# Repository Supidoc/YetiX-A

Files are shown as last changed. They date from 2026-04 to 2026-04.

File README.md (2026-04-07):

# YetiX-A

Small development board for the NXP MCX-A series MCUs.

YetiX-A is designed to be compact while still exposing most peripherals needed for firmware development, board bring-up, and protocol testing.

## Features

- SPI EEPROM
- SPI micro SD card slot
- CAN transceiver with optional bus termination
- USB-C connector with ISP button support
- 42 board pins exposing almost all MCU peripherals
- 10-pin ARM Cortex debug connector

## Pin Out

Most MCU pins are routed directly to board pins.

Some signals (for example SPI1 MISO, MOSI, and SCK) are internally connected to onboard peripherals and are still exposed as board pins. Other signals (for example debug pins and chip select lines) are only internally connected and not exposed.

For the exact mapping of MCU pins to board pins, see:

- [assets/PIN_Functions.csv](assets/PIN_Functions.csv)

## Quick Start

1. Power the board via the USB-C receptecal or the 5V Pin
2. Connect a debugger to the 10-pin Cortex debug header, or use ISP mode over USB.
3. Flash a minimal firmware project (for example, a GPIO blink) to verify toolchain and board bring-up.

## Programming And Debug

### SWD/JTAG Debug Header

YetiX-A includes a 10-pin ARM Cortex debug connector for standard MCU debugging workflows.

Recommended usage:

1. Power the board from USB-C or the intended external source.
2. Connect your debug probe to the Cortex header.
3. Use your preferred IDE/debug server to connect and flash.

### USB ISP Mode

The board supports ISP using the USB-C interface.

Typical flow:

1. Hold the ISP button.
2. Connect USB or reset the target if already connected.
3. Release the button.
4. Drag and drop the .uf2 file to the mass storage device.

## Onboard Peripherals

### SPI EEPROM (ST M95256-DF)

- Intended for non-volatile parameter/configuration storage.
- Shares SPI1 bus with SD-card and other externally connected devices.

### SPI micro SD Slot

- Intended for logging, file storage, or data exchange.
- Shares SPI1 bus with EEPROM and other externally connected devices.
- Switch to detect card insertion.

### CAN Transceiver (NXP TJA1042BT)

- 5V CAN Transceiver
- Optional footprints for termination.

## Documentation And Design Files

### KiCad Source

- Schematic: [YetiX-A_DevBoard.kicad_sch](YetiX-A_DevBoard.kicad_sch)
- PCB: [YetiX-A_DevBoard.kicad_pcb](YetiX-A_DevBoard.kicad_pcb)
- Project: [YetiX-A_DevBoard.kicad_pro](YetiX-A_DevBoard.kicad_pro)

### Exported Documentation

- Schematic PDF: [FabData/YetiX-A_Schematic.pdf](FabData/YetiX-A_Schematic.pdf)
- PCB layout PDF: [FabData/YetiX-A_PCB_Layout.pdf](FabData/YetiX-A_PCB_Layout.pdf)

### Manufacturing Outputs

All Documents for fabrication can be found in [FabData](FabData)

## Hardware Revisions

| Revision | Date | Notes |
| --- | --- | --- |
| 0.0.1 | - | Initial production package |
| 0.0.2 | - | Added optional CAN Termination |

## License

See [LICENSE](LICENSE).

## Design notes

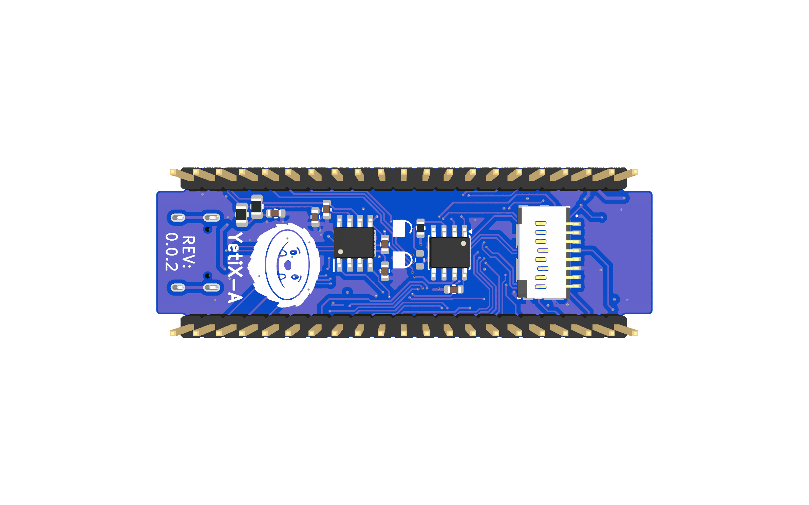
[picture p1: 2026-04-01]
FabData/dok/YetiX-A_bottom_view.png

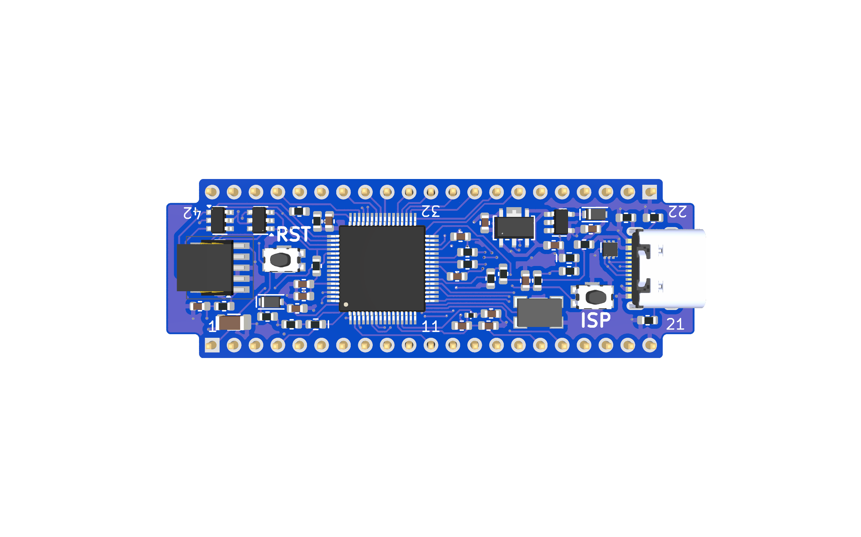
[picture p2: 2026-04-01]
FabData/dok/YetiX-A_top_view.png

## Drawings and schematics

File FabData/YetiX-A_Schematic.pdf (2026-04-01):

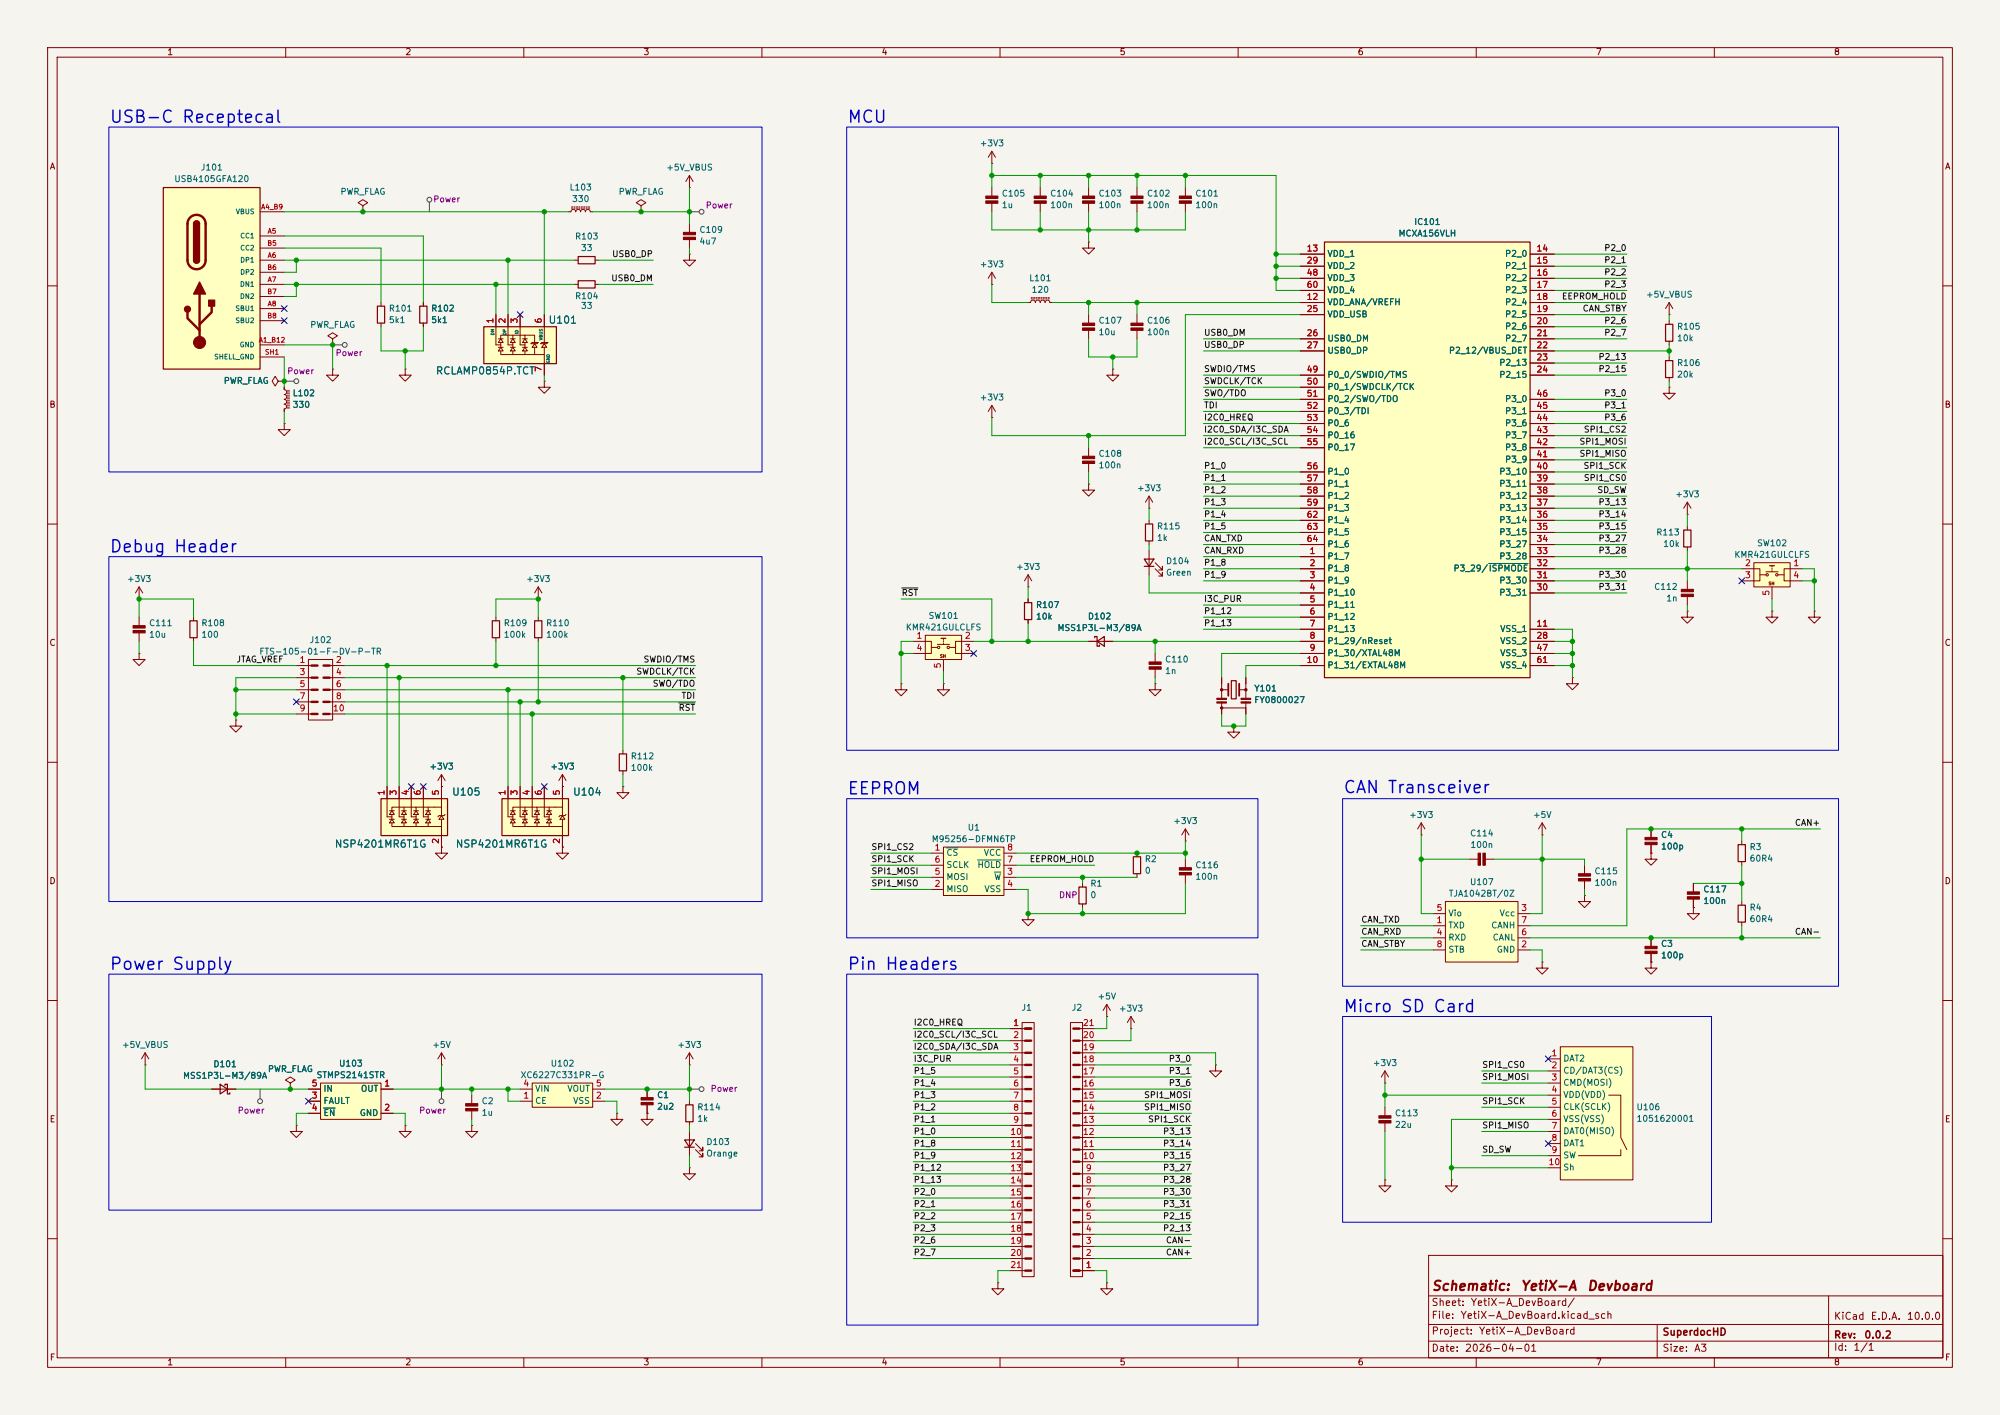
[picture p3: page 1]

5 | 6 | SWO/TDO

Sheet: YetiX-A_DevBoard/ File: YetiX-A_DevBoard.kicad_sch
Project: YetiX-A_DevBoard | SuperdocHD | KiCad E.D.A. 10.0.0 Rev: 0.0.2 | F Date: 2026-04-01

Size: A3 | Id: 1/1

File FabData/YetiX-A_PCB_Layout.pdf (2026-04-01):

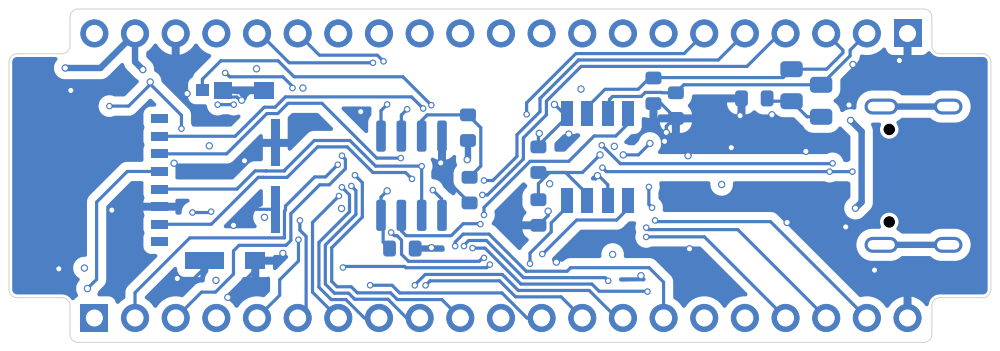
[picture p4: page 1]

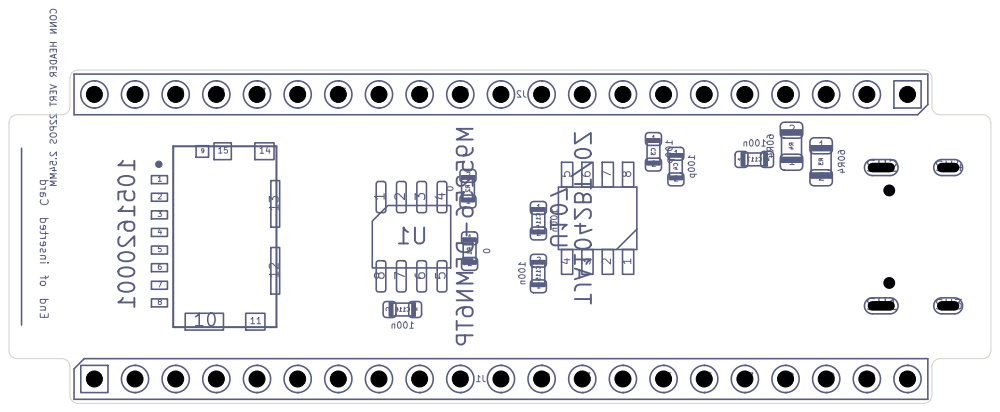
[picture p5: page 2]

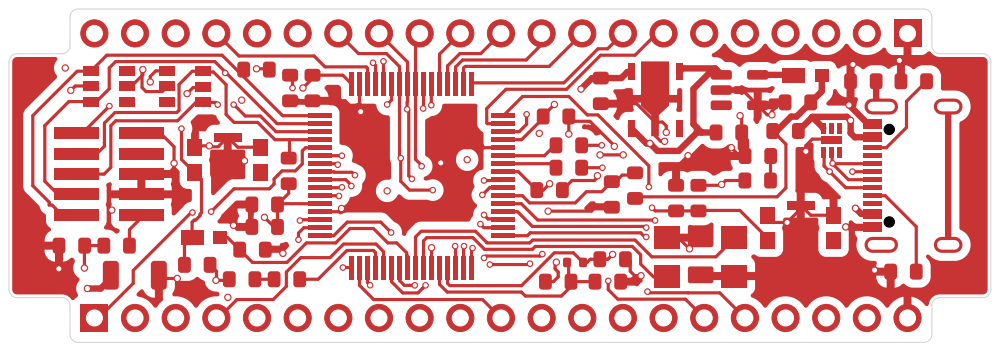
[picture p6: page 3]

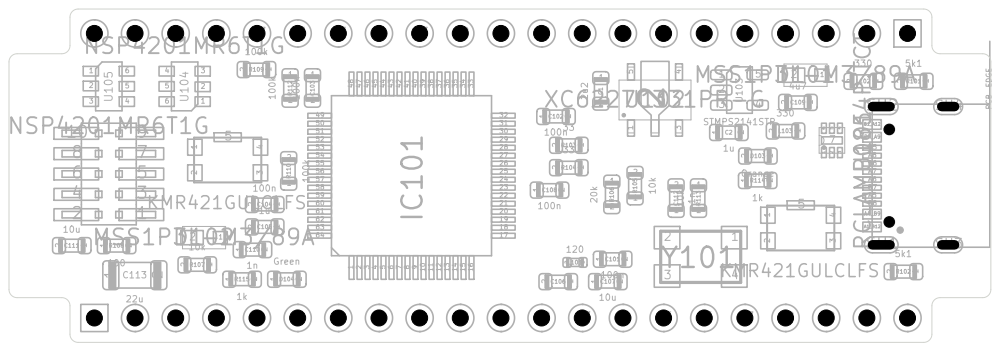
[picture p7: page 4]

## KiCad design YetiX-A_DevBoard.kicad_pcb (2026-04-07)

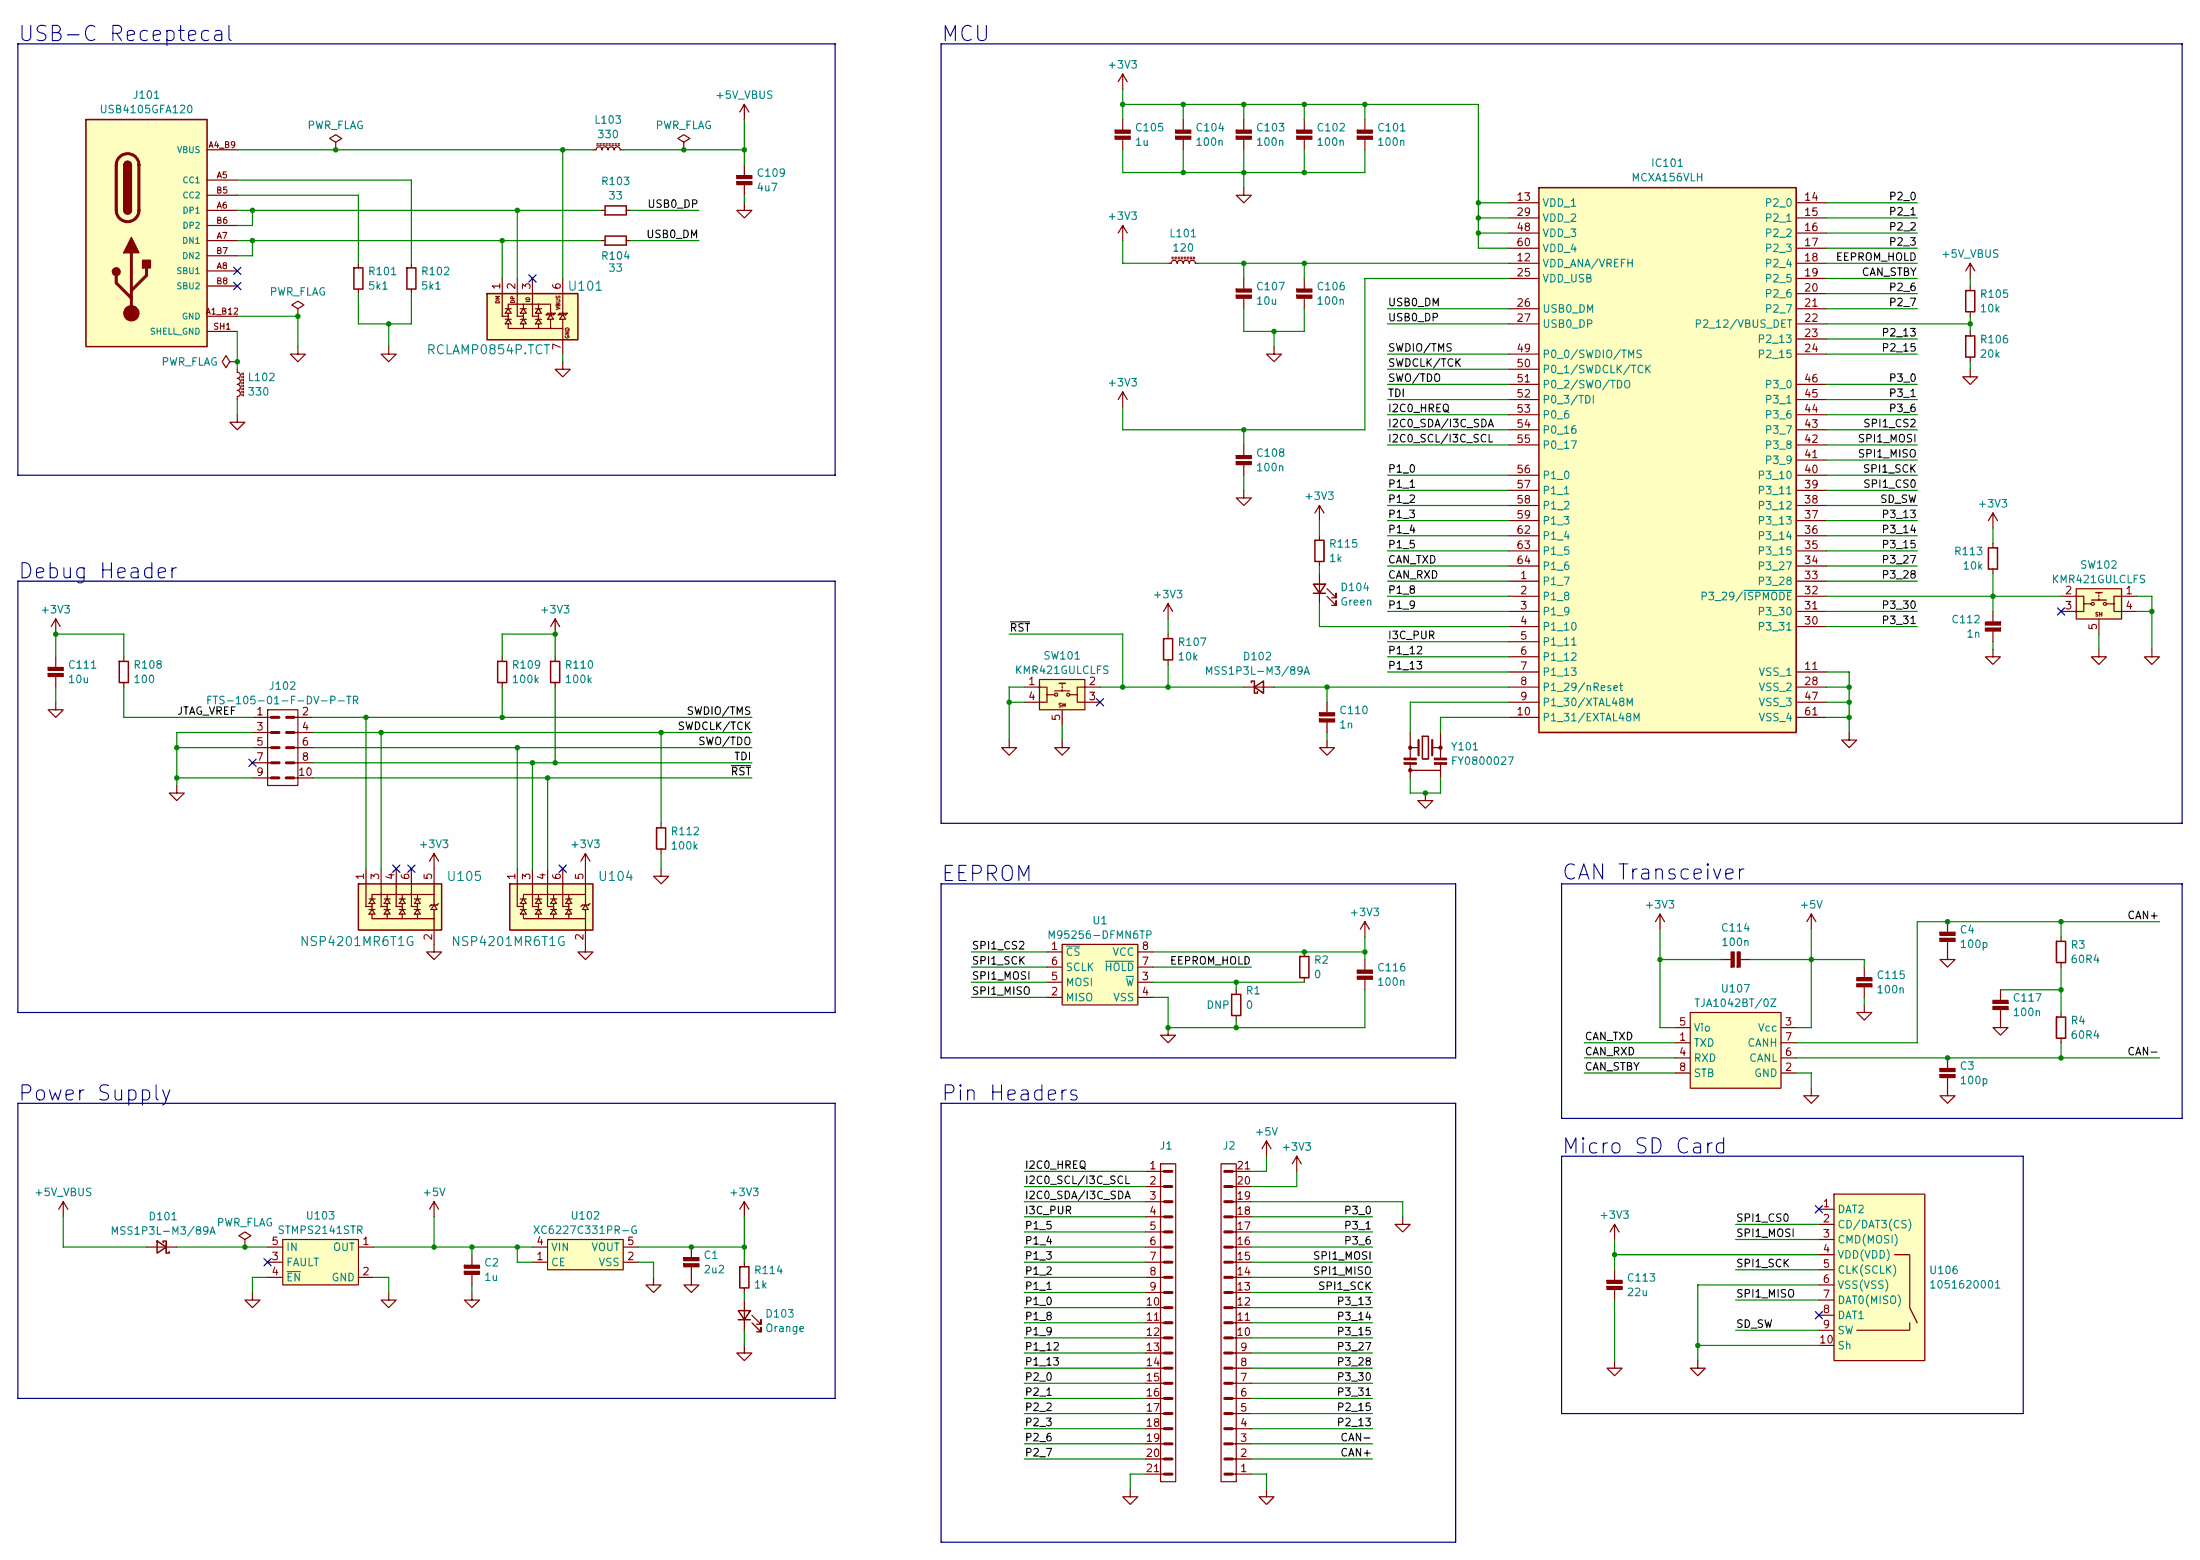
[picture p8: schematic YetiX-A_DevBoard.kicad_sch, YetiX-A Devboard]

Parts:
C1: 2u2; C_0603; Rating 10V 20%; MFR# CC0603KRX7R6BB225
C2, C105: 1u; C_0603; Rating 16V 10%; MFR# CC0603KRX7R7BB105
C3, C4: 100p; C_0603; Rating 100V 10%; MFR# CC0603KRX7R0BB101
C101, C102, C103, C104, C106, C108, C114, C115, C116, C117: 100n; C_0603; Rating 16V 10%; MFR# CC0603KRX7R7BB104
C107, C111: 10u; C_0603; Rating 10V 20%; MFR# CC0603MRX5R6BB106
C109: 4u7; C_0603; Rating 16V 10%; MFR# CC0603KRX5R7BB475
C110, C112: 1n; C_0603; Rating 50V 10%; MFR# CC0603KRX7R9BB103
C113: 22u; C_1206; Rating 10V 10%; MFR# CC1206KKX5R6BB226
D101, D102: MSS1P3L-M3/89A; DIODE_MSMP; Rating 30V 1A; MFR# MSS1P3L-M3/89A
D103: Orange; D_0603; Rating 2v 20mA 605nm; MFR# LTST-C190KFKT
D104: Green; D_0603; Rating 2v1 20mA 569nm; MFR# LTST-C190GKT
IC101: MCXA156VLH; QFP50P1200X1200X160-64N; MFR# MCXA156VLH
J1, J2: CONN HEADER VERT 22POS 2.54MM; PinHeader_1x21_P2.54mm_Vertical; MFR# 61302211121
J101: USB4105GFA120; GCT_USB4105GFA120; Rating 16 Pin; MFR# USB4105-GF-A-120
J102: FTS-105-01-F-DV-P-TR; FTS-105-01-X-DV; Rating 1.27 Pitch; MFR# FTS-105-01-F-DV-P-TR
L101: 120; L_0402; Rating 25% 550mA; MFR# BLM15AG121SN1D
L102, L103: 330; L_0603; Rating 330 Ohms @ 100 MHz 1.7A 80mOhm; MFR# MPZ1608S331ATA00
R1: 0; R_0603_DNP
R2: 0; R_0603; Rating 100mW; MFR# RC0603JR-070RL
R3, R4: 60R4; R_0805; Rating 125mW, 1%; MFR# RC0805FR-0760R4L
R101, R102: 5k1; R_0603; Rating 100mW, 1%; MFR# RC0603FR-075K1L
R103, R104: 33; R_0603; Rating 100mW, 1%; MFR# RC0603FR-0733RL
R105, R107, R113: 10k; R_0603; Rating 100mW, 1%; MFR# RC0603FR-0710KL
R106: 20k; R_0603; Rating 100mW, 1%; MFR# RC0603FR-0720KL
R108: 100; R_0603; Rating 100mW, 1%; MFR# RC0603FR-07100RL
R109, R110, R112: 100k; R_0603; Rating 100mW, 1%; MFR# RC0603FR-07100KL
R114, R115: 1k; R_0603; Rating 100mW, 1%; MFR# RC0603FR-071KL
SW101, SW102: KMR421GULCLFS; Rating 1VA; MFR# KMR421GULCLFS
U1: M95256-DFMN6TP; SOIC-8_3.9x4.9mm_P1.27mm; Rating 32kx8b 20MHZ; MFR# M95256-DFMN6TP
U101: RCLAMP0854P.TCT; UFDFN06_1P6X1P6; Rating 5.5VWM 30VC; MFR# RCLAMP0854P.TCT
U102: XC6227C331PR-G; SOT-89-5; Rating 700mA 3v3; MFR# XC6227C331PR-G
U103: STMPS2141STR; SOT-23-5; Rating 500mA; MFR# STMPS2141STR
U104, U105: NSP4201MR6T1G; TSOP-6; Rating 4 Channel 3pF @ 1MHz; MFR# NSP4201MR6T1G
U106: 1051620001; MFR# 1051620001
U107: TJA1042BT/0Z; SOT96-1; Rating 5 mbps; MFR# TJA1042BT/0Z
Y101: FY0800027; Rating 8 MHz ±20ppm; MFR# FY0800027

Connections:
+3V3: C1.1, C101.1, C102.1, C103.1, C104.1, C105.1, C108.1, C111.1, C113.1, C114.1, C116.2, IC101.13 (VDD_1), IC101.25 (VDD_USB), IC101.29 (VDD_2), IC101.48 (VDD_3), IC101.60 (VDD_4), J2.20, L101.1, R2.1, R107.1, R108.1, R109.1, R110.1, R113.1, R114.1, R115.1, U1.8 (VCC), U102.5 (VOUT), U104.5 (Vp), U105.5 (Vp), U106.4 (VDD(VDD)), U107.5 (Vio)
+5V: C2.1, C114.2, C115.2, J2.21, U102.1 (CE), U102.4 (VIN), U103.1 (OUT), U107.3 (Vcc)
+5V_VBUS: C109.1, D101.1 (K), L103.2, R105.1
/CAN+: C4.1, J2.2, R3.1, U107.7 (CANH)
/CAN-: C3.1, J2.3, R4.2, U107.6 (CANL)
/CAN_RXD: IC101.1 (P1_7), U107.4 (RXD)
/CAN_STBY: IC101.19 (P2_5), U107.8 (STB)
/CAN_TXD: IC101.64 (P1_6), U107.1 (TXD)
/EEPROM_HOLD: IC101.18 (P2_4), U1.7 (~HOLD)
/I2C0_HREQ: IC101.53 (P0_6), J1.1
/I2C0_SCL/I3C_SCL: IC101.55 (P0_17), J1.2
/I2C0_SDA/I3C_SDA: IC101.54 (P0_16), J1.3
/I3C_PUR: IC101.5 (P1_11), J1.4
/JTAG_VREF: J102.1, R108.2
/P1_0: IC101.56 (P1_0), J1.10
/P1_1: IC101.57 (P1_1), J1.9
/P1_2: IC101.58 (P1_2), J1.8
/P1_3: IC101.59 (P1_3), J1.7
/P1_4: IC101.62 (P1_4), J1.6
/P1_5: IC101.63 (P1_5), J1.5
/P1_8: IC101.2 (P1_8), J1.11
/P1_9: IC101.3 (P1_9), J1.12
/P1_12: IC101.6 (P1_12), J1.13
/P1_13: IC101.7 (P1_13), J1.14
/P2_0: IC101.14 (P2_0), J1.15
/P2_1: IC101.15 (P2_1), J1.16
/P2_2: IC101.16 (P2_2), J1.17
/P2_3: IC101.17 (P2_3), J1.18
/P2_6: IC101.20 (P2_6), J1.19
/P2_7: IC101.21 (P2_7), J1.20
/P2_13: IC101.23 (P2_13), J2.4
/P2_15: IC101.24 (P2_15), J2.5
/P3_0: IC101.46 (P3_0), J2.18
/P3_1: IC101.45 (P3_1), J2.17
/P3_6: IC101.44 (P3_6), J2.16
/P3_13: IC101.37 (P3_13), J2.12
/P3_14: IC101.36 (P3_14), J2.11
/P3_15: IC101.35 (P3_15), J2.10
/P3_27: IC101.34 (P3_27), J2.9
/P3_28: IC101.33 (P3_28), J2.8
/P3_30: IC101.31 (P3_30), J2.7
/P3_31: IC101.30 (P3_31), J2.6
/SD_SW: IC101.38 (P3_12), U106.9 (SW)
/SPI1_CS0: IC101.39 (P3_11), U106.2 (CD/DAT3(CS))
/SPI1_CS2: IC101.43 (P3_7), U1.1 (~CS)
/SPI1_MISO: IC101.41 (P3_9), J2.14, U1.2 (MISO), U106.7 (DAT0(MISO))
/SPI1_MOSI: IC101.42 (P3_8), J2.15, U1.5 (MOSI), U106.3 (CMD(MOSI))
/SPI1_SCK: IC101.40 (P3_10), J2.13, U1.6 (SCLK), U106.5 (CLK(SCLK))
/SWDCLK/TCK: IC101.50 (P0_1/SWDCLK/TCK), J102.4, R112.1, U105.3 (I/O)
/SWDIO/TMS: IC101.49 (P0_0/SWDIO/TMS), J102.2, R109.2, U105.1 (I/O)
/SWO/TDO: IC101.51 (P0_2/SWO/TDO), J102.6, U104.1 (I/O)
/TDI: IC101.52 (P0_3/TDI), J102.8, R110.2, U104.3 (I/O)
/USB0_DM: IC101.26 (USB0_DM), R104.2
/USB0_DP: IC101.27 (USB0_DP), R103.2
/~RST: D102.2 (K), J102.10, R107.2, SW101.2, U104.4 (I/O)
GND: C1.2, C2.2, C3.2, C4.2, C101.2, C102.2, C103.2, C104.2, C105.2, C106.2, C107.2, C108.2, C109.2, C110.2, C111.2, C112.2, C113.2, C115.1, C116.1, C117.1, D103.2 (K), IC101.11 (VSS_1), IC101.28 (VSS_2), IC101.47 (VSS_3), IC101.61 (VSS_4), J1.21, J2.1, J2.19, J101.A1_B12 (GND), J101.B1_A12 (GND), J102.3, J102.5, J102.9, L102.2, R1.2, R101.2, R102.2, R106.2, R112.2, SW101.1, SW101.4 (3), SW101.5 (SH), SW102.1, SW102.4 (3), SW102.5 (SH), U1.4 (VSS), U101.7 (GND), U102.2 (VSS), U103.2 (GND), U103.4 (~EN), U104.2 (Vn), U105.2 (Vn), U106.6 (VSS(VSS)), U106.10 (Sh), U106.11 (Sh), U106.12 (Sh), U106.13 (Sh), U106.14 (Sh), U106.15 (Sh), U107.2 (GND), Y101.2 (GND), Y101.4 (GND)
unnamed: C117.2, R3.2, R4.1
unnamed: D103.1 (A), R114.2
unnamed: D104.1 (A), R115.2
unnamed: D104.2 (K), IC101.4 (P1_10)
unnamed: C110.1, D102.1 (K), IC101.8 (P1_29/nReset)
unnamed: IC101.9 (P1_30/XTAL48M), Y101.1 (Crystal_1)
unnamed: IC101.10 (P1_31/EXTAL48M), Y101.3 (Crystal_1)
unnamed: IC101.22 (P2_12/VBUS_DET), R105.2, R106.1
unnamed: C112.1, IC101.32 (P3_29/~ISPMODE), R113.2, SW102.2
unnamed: C106.1, C107.1, IC101.12 (VDD_ANA/VREFH), L101.2
unnamed: J101.A5 (CC1), R102.1
unnamed: J101.B5 (CC2), R101.1
unnamed: J101.A7 (DN1), J101.B7 (DN2), R104.1, U101.1 (DM)
unnamed: J101.A6 (DP1), J101.B6 (DP2), R103.1, U101.2 (DP)
unnamed: R1.1, R2.2, U1.3 (~W)
unnamed: D101.2 (K), U103.5 (IN)
SHELL_GND: J101.SH1 (SHELL_GND), J101.SH2 (SHELL_GND), J101.SH3 (SHELL_GND), J101.SH4 (SHELL_GND), L102.1
VBUS: J101.A4_B9 (VBUS), J101.B4_A9 (VBUS), L103.1, U101.6 (VBUS)

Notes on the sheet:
MCU
Pin Headers
USB-C Receptecal
Micro SD Card
Debug Header
Power Supply
CAN Transceiver
EEPROM

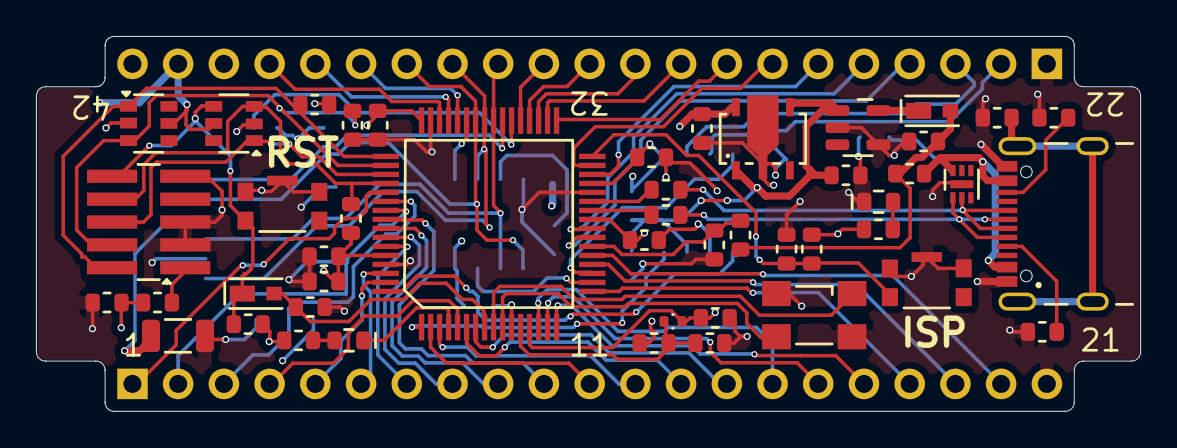
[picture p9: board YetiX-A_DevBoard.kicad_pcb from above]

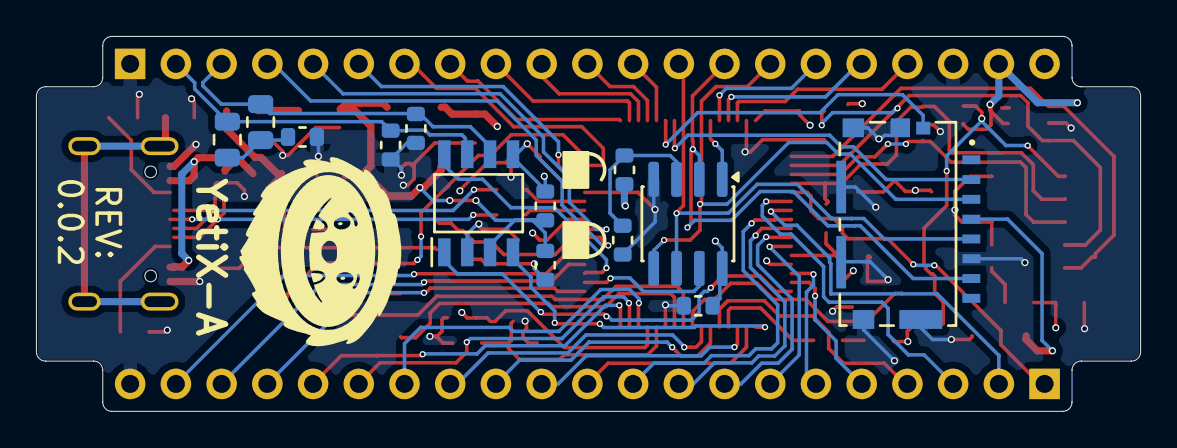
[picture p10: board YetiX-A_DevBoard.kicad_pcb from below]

Board: 4 copper layers, 61.3 x 20.8 mm, 62 parts (15 on the bottom side), 74 nets.

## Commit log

2026-03-31 Rev: 0.0.1
    [PIN_Functions.ods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]
2026-04-01 Rev: 0.0.2
    - Added filtering capacitors on CAN output.
    - Added optional CAN termination
    [YetiX-A_DevBoard-B_Cu.gbl, YetiX-A_DevBoard-B_Mask.gbs, YetiX-A_DevBoard-B_Paste.gbp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]
2026-04-07 QR-Code
    - Added QR-Code with link to github repository
    [YetiX-A_DevBoard.kicad_pcb]
2026-04-07 Pin FUnctions Table Update
    [PIN_Functions.csv, PIN_Functions.ods]
2026-04-07 Initial README
    [PIN_Functions.ods]
